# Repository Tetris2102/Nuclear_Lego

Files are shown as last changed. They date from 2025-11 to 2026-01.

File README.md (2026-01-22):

# Nuclear Lego - a Fun and Safe Nuclear Physics Tool

This is intended to be a modular system (base + cubes) which would make it  
easy to perform simple nuclear physics experiments without any radiation  
involved. The project is currently developed as a qualitative tool for  
demonstrations. However there is a large potential for customization, as this  
device is basically a particle transport solver with a physical real-time  
interface (cubes).  

Cubes (4 cm side) can be placed on a rectangular base. Every cube can represent  
either a radioactive source, material, or radiation detector. The base can  
contain 3 layers of 4 by 4 cubes maximum. Every cube can be programmed through  
I2C to change what it represents. Up to 256 types of isotopes and up to 256  
types of materials are supported, extending this is also possible. Radiation  
detectors can be programmed to detect any combination of alpha, beta, gamma  
and neutron radiation.

# Setup instructions
## Raspberry Pi 5:
1. Install g++ and cmake:
``` bash
sudo apt install g++ cmake
```
OpenMP should be included with g++ installation

2. Clone the repository and compile executable:
``` bash
cd ~
mkdir GitHub && cd GitHub
git clone https://github.com/Tetris2102/Nuclear_Lego
cd Nuclear_Lego
cd Particle_Transport
mkdir build && cd build
cmake ..
make
```

3. Ensure the executable has sufficient permissions
``` bash
sudo chmod +x ~/GitHub/Particle_Transport/build/nuclear_lego
```

4. Create systemd service to make the executable launch on system boot
``` bash
sudo nano /etc/systemd/system/nuclear_lego.system
```

Then paste the following into editor:
```
[Unit]
Description=Nuclear Lego main executable
After=network.target

[Service]
ExecStart=~/GitHub/Particle_Transport/build/nuclear_lego

[Install]
WantedBy=multi-user.target
```
Then save, exit and run the following:
``` bash
sudo systemctl daemon-reload
sudo systemctl enable nuclear_lego.service
sudo systemctl start nuclear_lego.service
```

5. Set poweroff button and make it act on the first press
To set poweroff button at GPIO pin 17:
``` bash
sudo nano /boot/firmware/config.txt
```

In editor, add the following line:
```
dtoverlay=gpio-shutdown,gpio_pin=17,gpio_pull=up,debounce=1000
```

To make the poweroff button act on first press:
``` bash
sudo nano /boot/firmware/cmdline.txt
```

In editor, add the following line:
```
command_poweroff=poweroff
```

Then REBOOT with
``` bash
sudo reboot
```

Now you can connect a poweroff button between GPIO pin 17 and ground.

7. (Optional) Enable SSH for easy access to Raspberry Pi
``` bash
sudo raspi-config
```
Go to Interfacing Options -> SSH -> Yes

Now you can access Raspberry Pi 5 through SSH. Assuming username is raspberrypi (default), on MacOS or Linux you can use
``` bash
ssh raspberrypi@raspberrypi.local
```
to access Raspberry Pi if it is one the same network as computer.

## Hardware:
1. Assemble cubes (3d printing, soldering and flashing software on ATTiny85).
It is convenient to use Arduino UNO via Arduino As ISP to program ATTiny 85

2. Assemble the base.
3D print base, then put in poweroff button and power status LED. Mount Raspberry Pi in place with 2 M3x6mm flathead bolts (M3 bolts used everywhere). Solder the 70x90 mm perf board with 2 I2C multiplexers and a level shifter and screw it in with a 3d-printed frame and four M3x6mm flathead bolts. Put header pins in corresponding openings in base lid and solder 30 cm wires with female ports at the other end. Wire everything accordingly. Screw on the lid with eight M3x10mm flathead bolts.

Here is the circuit diagram for base:
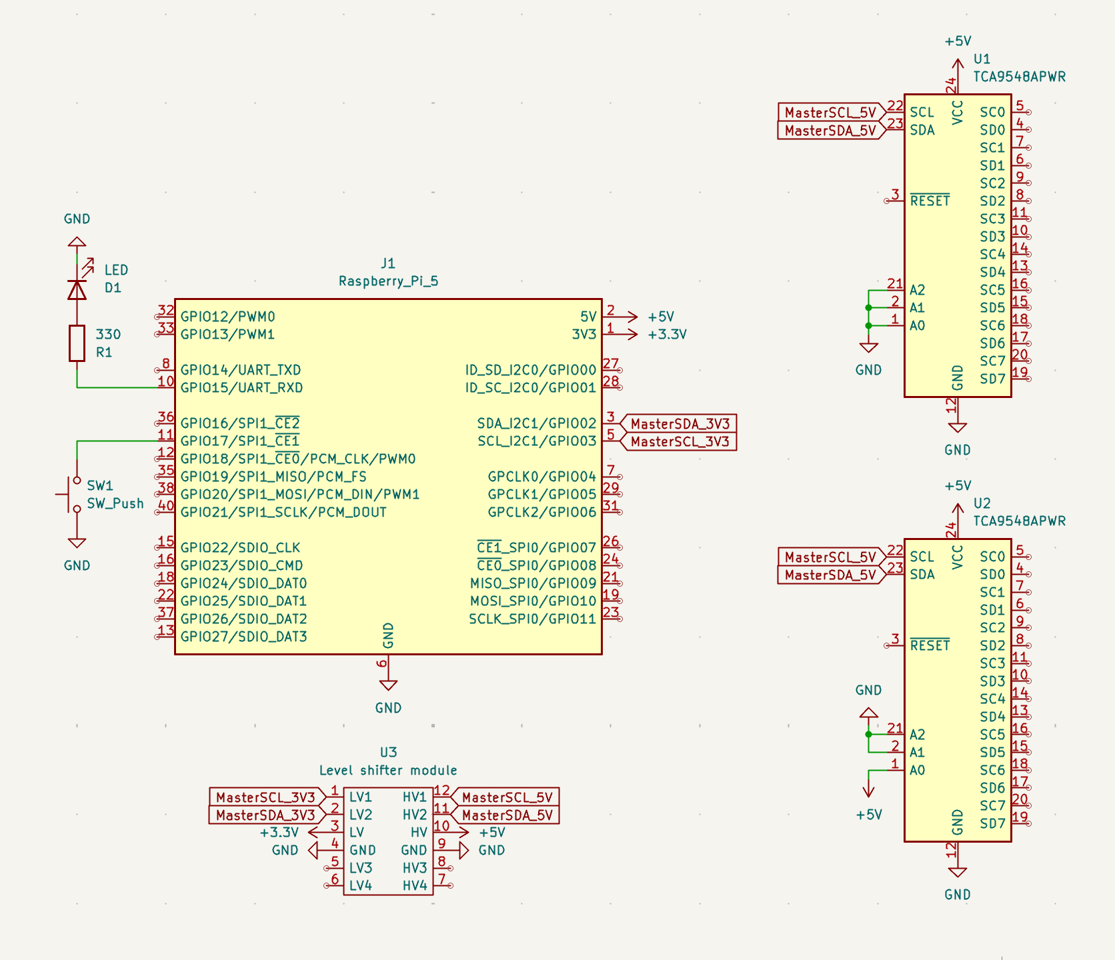
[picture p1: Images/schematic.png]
Failed to load image


(I2C channels 0-7 of multiplexer U1 are connected to voxel slots 0-7, I2C channels 0-7 of multiplexer U2 are connected to voxel slots 8-15)

4. You should be good to go unless any major mistakes were made in the process!

# Usage
1. Now if you have at least two cubes, you can program one to be source and the other to be a detector with an Arduino Uno or Nano via I2C (see cube_attiny85.ino and test_write.ino for programming via I2C).
2. If you put these cubes close to each other on the base, or on top of each other, the detector should produce increased counts with its buzzer.
3. With 3 cubes or more and by adding more reactions/scatters/absorbs to data.cpp you should be able to experiment with particle absorbtion, reflection, production, fission, criticality, and more! Don't forget to recompile after any data was modified for changes to take effect.

# Credits:
1. My parents and my wonderful Special Projects teacher  
2. https://grabcad.com/library/double-sided-fr-4-perfboards-w-m2-corners-1  
3. https://grabcad.com/library/raspberry-pi-5-model-1  
4. https://pip-assets.raspberrypi.com/categories/892-raspberry-pi-5/documents/RP-008347-DS-1-raspberry-pi-5-mechanical-drawing.pdf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

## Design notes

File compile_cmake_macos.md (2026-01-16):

MacOS compilation instructions (error checking ONLY):

1. Install MacPorts (if not already)

2. Install clang and OpenMP through MacPorts:
``` bash
sudo port install g++-15
sudo port install libomp
```

3. Clone the repository in your folder of choice, e.g.:
``` bash
cd ~
git clone https://github.com/Tetris2102/Nuclear_Lego
```

4. Compile using CMake:
Intel MacOS:
``` bash
mkdir Nuclear_Lego/Particle_transport/build
cd Nuclear_Lego/Particle_transport/build
export DCMAKE_CXX_COMPILER=/usr/local/bin/g++-15
cmake -DCMAKE_CXX_COMPILER=/usr/local/bin/g++-15 ..
make
```

Apple Silicon MacOS:
``` bash
mkdir Nuclear_Lego/Particle_transport/build
cd Nuclear_Lego/Particle_transport/build
export DCMAKE_CXX_COMPILER=/opt/homebrew/bin/g++-15
cmake -DCMAKE_CXX_COMPILER=/opt/homebrew/bin/g++-15 ..
make
```

Please note this is for debugging only and you will anyway receive an error:
``` bash
.../pi5_main.cpp:8:10: fatal error: linux/i2c-dev.h: No such file or directory
    8 | #include <linux/i2c-dev.h>
      |          ^~~~~~~~~~~~~~~~~
```

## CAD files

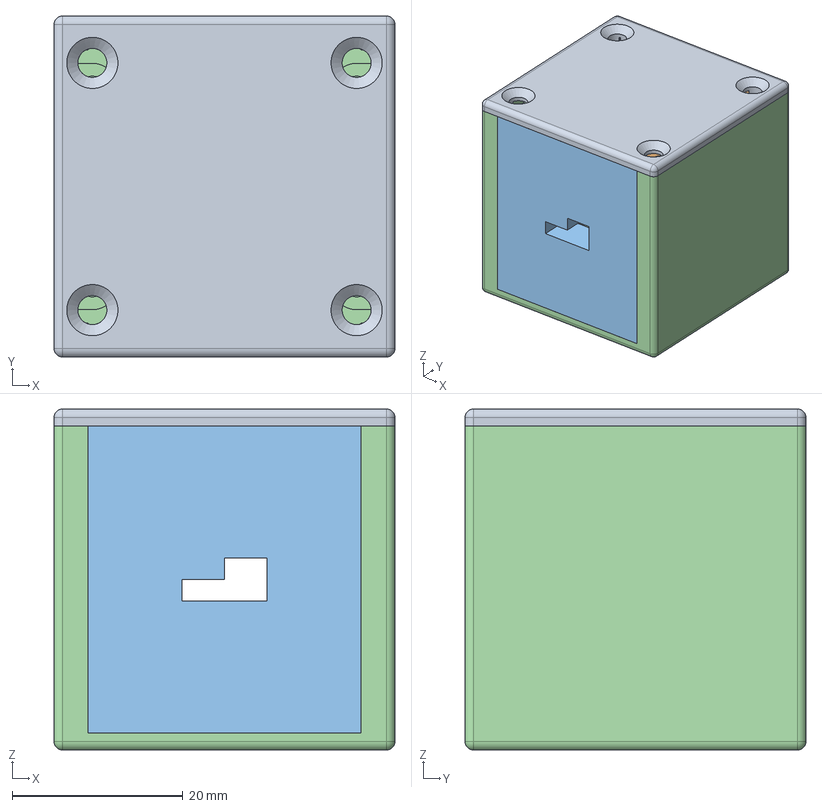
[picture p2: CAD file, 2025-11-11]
Cube_Hardware/case/models/cube_full.step
40.0 x 40.0 x 40.0 mm

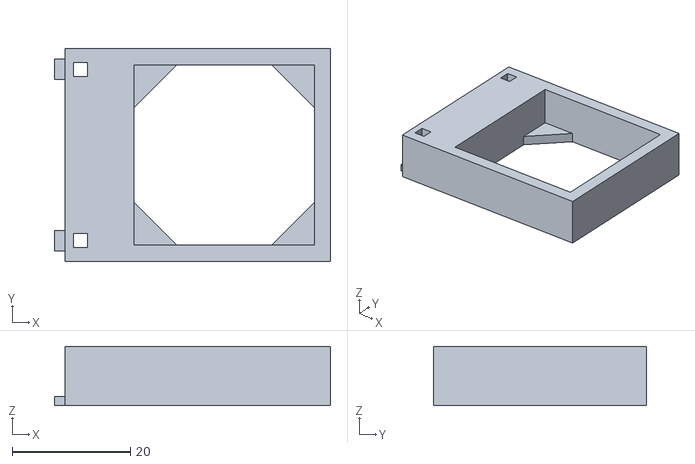
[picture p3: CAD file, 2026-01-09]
Base_Hardware/3D printing sent on Dec.12/FanHolder.stl
46.7 x 36.0 x 10.0

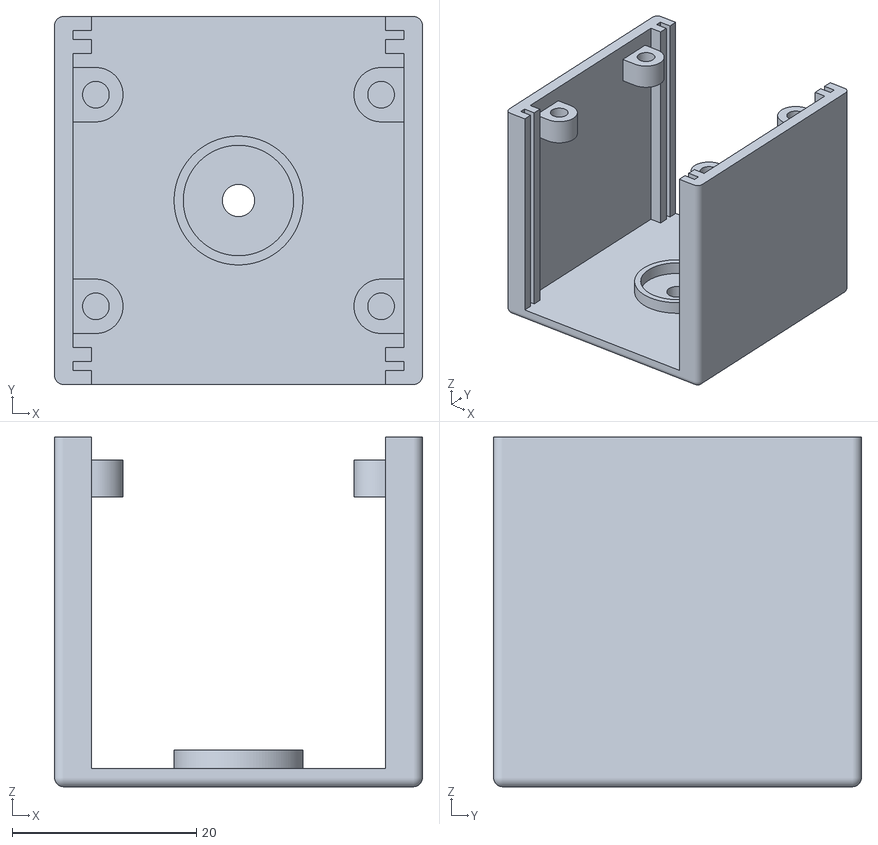
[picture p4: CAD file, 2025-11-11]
Cube_Hardware/case/3dprint/cube_base.stl
40.0 x 40.0 x 38.0

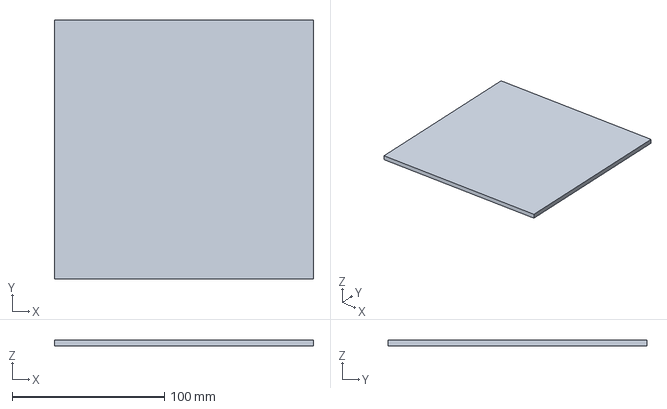
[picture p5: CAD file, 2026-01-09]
Cube_Hardware/case/newAttempt.FCStd
170.0 x 170.0 x 4.00 mm

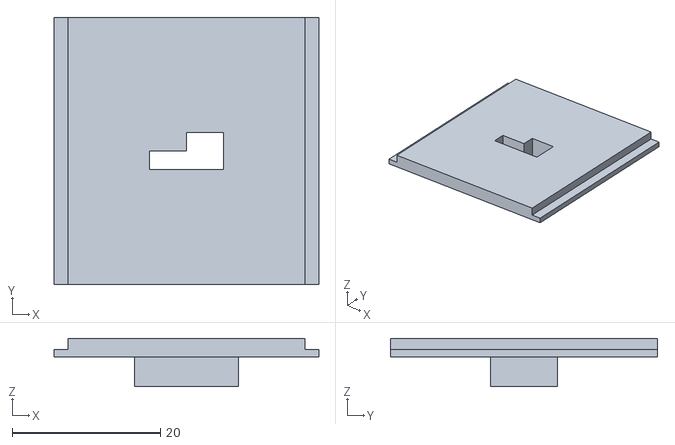
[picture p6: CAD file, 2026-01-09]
Cube_Hardware/case/Nov.17_version/wall1.stl
35.7 x 36.0 x 6.50

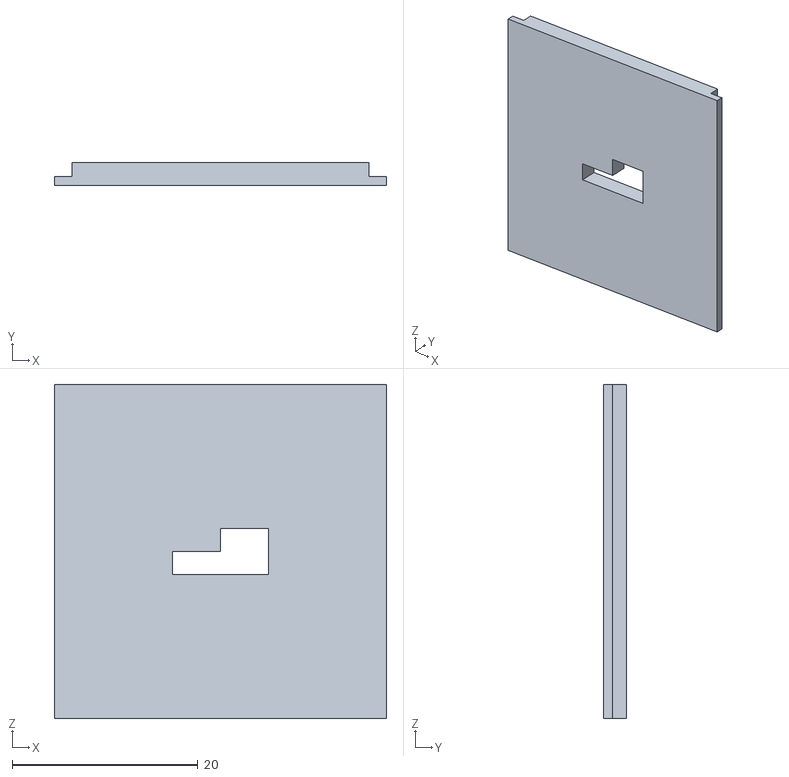
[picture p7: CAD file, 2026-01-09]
Cube_Hardware/case/Nov.24_version/wall2.stl
35.7 x 2.50 x 36.0

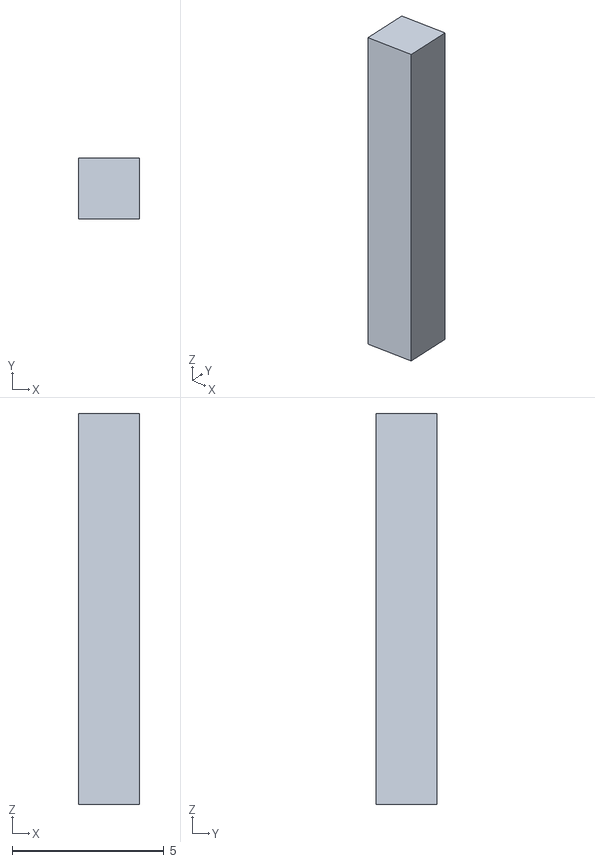
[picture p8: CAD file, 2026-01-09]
Base_Hardware/3D printing sent on Dec.12/Rivet1.stl
2.00 x 2.00 x 12.9

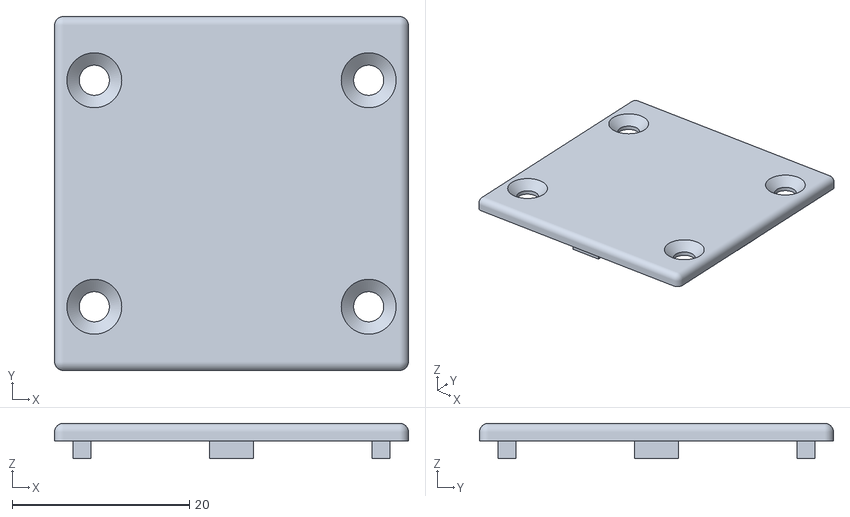
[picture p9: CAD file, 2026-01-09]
Cube_Hardware/case/Nov.24_version/lid.stl
40.0 x 40.0 x 4.00

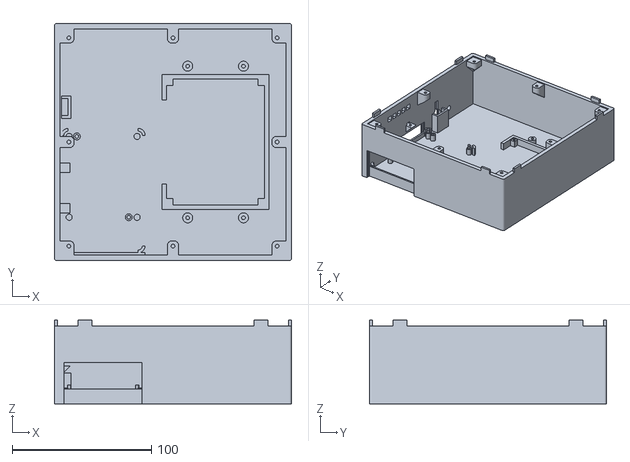
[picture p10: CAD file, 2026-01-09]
Base_Hardware/3D printing sent on Dec.12/BaseBottom.stl
170.0 x 170.0 x 60.0

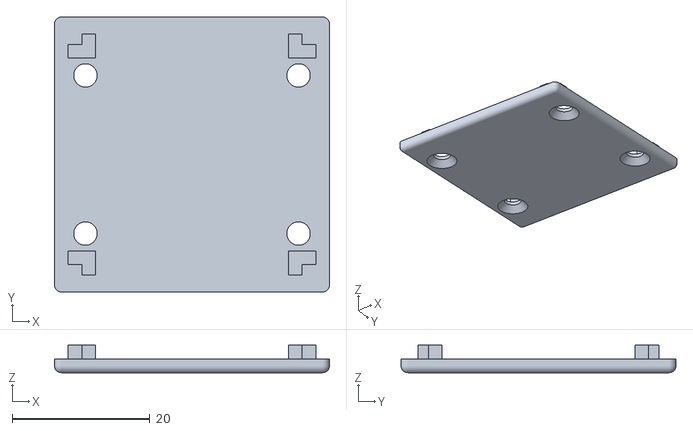
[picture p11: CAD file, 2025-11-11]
Cube_Hardware/case/3dprint/cube_lid.stl
40.0 x 40.0 x 4.00

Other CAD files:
Cube_Hardware/case/Nov.27_version/lid v7.step
Cube_Hardware/case/3dprint/cube_side_female.stl
Cube_Hardware/case/models/cube_case.FCStd
Cube_Hardware/case/Nov.17_version/wall2.stl
Cube_Hardware/case/3dprint/cube_side_male.stl
Cube_Hardware/case/Nov.17_version/base.stl
Cube_Hardware/case/Nov.24_version/body.stl
Base_Hardware/3D printing sent on Dec.12/Rivet2.stl
Base_Hardware/3D printing sent on Dec.12/BaseLid.stl
Base_Hardware/3D printing sent on Dec.12/PCBHolder.stl
Cube_Hardware/case/Nov.17_version/case.step
Cube_Hardware/case/Nov.17_version/lid.stl
Cube_Hardware/case/Nov.24_version/cube_case.step
Cube_Hardware/case/Nov.24_version/wall1.stl
Cube_Hardware/case/old versions/cube_all_improved.step
Cube_Hardware/case/old versions/cube_assembly_Nov.17.f3d
Cube_Hardware/case/old versions/cube_assembly_Nov.17.step
Cube_Hardware/case/old versions/cube_case.FCStd

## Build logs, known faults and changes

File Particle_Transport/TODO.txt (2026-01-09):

-3. Include dist and gen as mandatory constructor parameters in Voxel
    to avoid segmentation fault because of null pointers (instead of using setRNG())
-2. Make all functions const member where possible, especially in Voxel
-1. pointAlongVec() and moveToPointAlong() moved from helpers.cpp
  to particle.cpp -> make corresponding changes - DONE
0. Add moveToPointAlong() to ParticleGroup instead of helpers.cpp - DONE
1. Replace std::array<float, 3> with struct Vec3 - DONE
2. Adjust data types where float is excessive (if needed)
3. Explicitly include all used headers in every implementation file
instead of chaining #include in files - NO NEED?
4. Finish data.cpp

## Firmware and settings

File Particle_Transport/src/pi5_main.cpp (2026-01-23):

// pi5_main.cpp

#include "world.h"
#include "data.cpp"
#include "enums.h"
#include <fcntl.h>
#include <sys/ioctl.h>
#include <linux/i2c-dev.h>
#include <csignal>
#include <array>
#include <vector>
#include <unistd.h>
#include <iostream>
#include <iomanip>
#include <thread>
#include <chrono>

#define MUX1_ADDR 0x70
#define MUX2_ADDR 0x71

using namespace std;

// Global variables
int fd = -1;
std::chrono::duration<float> lastIterationTook;
vector<Material> materials;
vector<IsotopeSample> isotopeSamples;
World* worldPtr = nullptr;

vector<Voxel*> createAirFilledScene(int size) {
    vector<Voxel*> airScene;
    airScene.reserve(size);
    Material air = getM_Air();

    for(uint8_t i=0; i<size; i++) {
        airScene.push_back(new Voxel{MATTER, air});
    }
    return airScene;
}

Material getMaterialFromInt(uint8_t idx) {
    if(idx >= materials.size()) {
        cerr << "Error: Material index " << (int)idx << " out of bounds (size: "
             << materials.size() << ")" << endl;
        return getM_Air();  // Return default material
    }
    return materials[idx];
}

IsotopeSample getSampleFromInt(uint8_t idx) {
    if(idx >= isotopeSamples.size()) {
        cerr << "Error: IsotopeSample index " << (int)idx << " out of bounds (size: "
             << isotopeSamples.size() << ")" << endl;
        return getS_NULL();  // Return default sample
    }
    return isotopeSamples[idx];
}

vector<ParticleType> partsListFromInt(uint8_t val) {
    vector<ParticleType> partsList;
    for(uint8_t i=0; i<8; i++) {
        if(((1 << i) & val) != 0) {
            partsList.push_back(static_cast<ParticleType>(i));
        }
    }
    return partsList;
}

void recordCubeDataTo(vector<Voxel*>& sceneToWrite,
  array<uint8_t, 5>& cubeData, int x, int y) {
    uint8_t z = cubeData[4];

    // Safety check: ensure worldPtr is initialized
    if(worldPtr == nullptr) {
        cerr << "Error: worldPtr is nullptr in recordCubeDataTo()" << endl;
        return;
    }

    // Validate z coordinate (world is 4x4x3, so z must be 0, 1, or 2)
    if(z >= 4) {
        cerr << "Warning: Invalid z coordinate " << (int)z
             << " from cube at (" << x << ", " << y << ")" << endl;
        return;
    }

    // Validate x and y coordinates
    if(x < 0 || x >= 4 || y < 0 || y >= 4) {
        cerr << "Warning: Invalid coordinates ("
            << x << ", " << y << ", " << (int)z << ")" << endl;
        return;
    }

    auto voxelEntryPtr = worldPtr->voxelEntryAt(x, y, z);
    if(voxelEntryPtr == nullptr) {
        cerr << "Error: voxelEntryAt() returned nullptr for ("
             << x << ", " << y << ", " << (int)z << ")" << endl;
        return;
    }

    if(voxelEntryPtr->vPtr == nullptr) {
        cerr << "Error: vPtr is nullptr for voxel at ("
             << x << ", " << y << ", " << (int)z << ")" << endl;
        return;
    }

    auto* voxelPtr = voxelEntryPtr->vPtr;
    VoxelType voxelType = static_cast<VoxelType>(cubeData[0]);

    // // Don't overwrite manually configured detectors (preserve test detectors)
    // // Only update if the cube is actually configured as a detector in hardware
    // if(voxelPtr->getType() == DETECTOR && voxelType != DETECTOR) {
    //     // Skip overwriting - preserve existing detector configuration
    //     return;
    // }
    
    voxelPtr->setType(voxelType);
    voxelPtr->setMaterial(getMaterialFromInt(cubeData[1]));
    if(voxelType == DETECTOR) {
        voxelPtr->setIsotopeSample(getSampleFromInt(cubeData[2]));
        voxelEntryPtr->setPartsDetectable(partsListFromInt(cubeData[3]));
    }
}

void signalInterrupt(int sig) {
    (void)sig;  // Suppress unused parameter warning
    cout << "Exiting program..." << endl;
    if(fd >= 0) {
        close(fd);
    }
    cout << "Done." << endl;
    exit(0);
}

// 4x4x3 (x, y, z) cube world, each cube has a side of 4.0 cm
World world(4, 4, 3, 4.0);

int main() {

    // Handle system shutdown or program termination
    signal(SIGTERM, signalInterrupt);
    signal(SIGINT, signalInterrupt);

    materials = getMaterials();
    isotopeSamples = getIsotopeSamples();
    worldPtr = &world;

    Material air_mat = getM_Air();

    IsotopeSample testSample = getS_Sr90();  // DELETE LINE IN FINAL IMPLEMENTATION
    Voxel testSampleVoxel(SOURCE, air_mat, testSample);  // DELETE LINE IN FINAL IMPLEMENTATION

    vector<Voxel*> scene = createAirFilledScene(48);
    scene[6] = &testSampleVoxel;  // DELETE LINE IN FINAL IMPLEMENTATION
    // scene[6] is at position (2, 1, 0) for 4x4x3 world: index = x + 4*(y + 3*z) = 2 + 4*(1 + 0) = 6

    // Create a test detector near the source (at position 7 = (3, 1, 0))
    Voxel testDetectorVoxel(DETECTOR, air_mat);
    scene[7] = &testDetectorVoxel;  // DELETE LINE IN FINAL IMPLEMENTATION
    world.setScene(scene);

    // Configure detector to detect beta particles (Sr90 emits beta)
    auto* detectorEntry = world.voxelEntryAt(3, 1, 0);
    if(detectorEntry) {
        vector<ParticleType> detectable = {BETA};
        detectorEntry->setPartsDetectable(detectable);
        cout << "Configured detector at (3, 1, 0) to detect BETA particles" << endl;
    }

    const char* dev = "/dev/i2c-1";

    fd = open(dev, O_RDWR);
    if(fd < 0) {
        cerr << "Error: Failed to initialize i2c on master" << endl;
        return 1;
    }

    // Deselect all channels at MUX 1
    unsigned char muxData = 0b00000000;
    if(ioctl(fd, I2C_SLAVE, MUX1_ADDR) < 0) {
        cerr << "Error: Failed to set MUX1 slave address on init" << endl;
        return 1;
    }
    if(write(fd, &muxData, 1) < 1) {
        cerr << "Error: Failed to deselect MUX 2 chanels on init" << endl;
    }

    // Deselect all channels at MUX 2
    if(ioctl(fd, I2C_SLAVE, MUX2_ADDR) < 0) {
        cerr << "Error: Failed to set MUX2 slave address on init" << endl;
        return 1;
    }
    if(write(fd, &muxData, 1) < 1) {
        cerr << "Error: Failed to deselect MUX 2 chanels on init" << endl;
    }

    while(true) {

        auto start = chrono::high_resolution_clock::now();

        // currentCubeData = [voxelType, materialType,
        // sampleType, particlesDetectable, level]
        array<uint8_t, 5> currentCubeData;
        int muxChannelNum = 0;
        for(uint8_t x=0; x<4; x++) {
            for(uint8_t y=0; y<4; y++) {
                muxChannelNum = y * 4 + (x + 1) - 1;  // Channels numbered 0 to 15
                if(muxChannelNum < 8) {

                    // Select MUX1 channel (muxChannelNum 1-8 maps to mux channels 0-7)
                    if(ioctl(fd, I2C_SLAVE, MUX1_ADDR) < 0) {
                        cerr << "Error: Failed to set MUX1 slave address" << endl;
                        continue;
                    }
                    muxData = 1 << muxChannelNum;
                    if(write(fd, &muxData, 1) < 1) {
                        cerr << "Error: Failed to write to MUX1" << endl;
                        continue;
                    }
                    usleep(1000);  // Small delay for mux to settle

                    // Read from each level (addresses 8, 9, 10)
                    for(uint8_t i2c_addr=8; i2c_addr<11; i2c_addr++) {
                        if(ioctl(fd, I2C_SLAVE, i2c_addr) < 0) continue;
                        int bytesRead = read(fd, currentCubeData.data(), 5);
                        if(bytesRead == 5) {
                            recordCubeDataTo(scene, currentCubeData, x, y);
                        } else if(bytesRead > 0) {
                            cerr << "Warning: Only read " << bytesRead
                                << " bytes from 0x" << hex << (int)i2c_addr << endl;
                        }
                    }

                    // Deselect MUX1
                    if(ioctl(fd, I2C_SLAVE, MUX1_ADDR) < 0) {
                        cerr << "Error: Failed to set MUX1 slave address" << endl;
                        continue;
                    }
                    muxData = 0b00000000;
                    if(write(fd, &muxData, 1) < 1) {
                        cerr << "Error: Failed to write to MUX1" << endl;
                    }

                } else if (muxChannelNum < 16) {

                    // Select MUX2 channel
                    if(ioctl(fd, I2C_SLAVE, MUX2_ADDR) < 0) {
                        cerr << "Error: Failed to set MUX2 slave address" << endl;
                        continue;
                    }
                    muxData = 1 << (muxChannelNum - 8);
                    if(write(fd, &muxData, 1) < 1) {
                        cerr << "Error: Failed to write to MUX2" << endl;
                        continue;
                    }
                    usleep(1000);  // Small delay for mux to settle

                    // Read from each level (addresses 8, 9, 10)
                    for(uint8_t i2c_addr=8; i2c_addr<11; i2c_addr++) {
                        if(ioctl(fd, I2C_SLAVE, i2c_addr) < 0) continue;
                        int bytesRead = read(fd, currentCubeData.data(), 5);
                        if(bytesRead == 5) {
                            recordCubeDataTo(scene, currentCubeData, x, y);
                        } else if(bytesRead > 0) {
                            cerr << "Warning: Only read " << bytesRead
                                << " bytes from 0x" << hex << (int)i2c_addr << endl;
                        }
                    }

                    // Deselect MUX2
                    if(ioctl(fd, I2C_SLAVE, MUX2_ADDR) < 0) {
                        cerr << "Error: Failed to set MUX2 slave address" << endl;
                        continue;
                    }
                    muxData = 0b00000000;
                    if(write(fd, &muxData, 1) < 1) {
                        cerr << "Error: Failed to write to MUX2" << endl;
                    }

                } else {

                    cerr << "Error: Invalid multiplexer channel number: "
                        << muxChannelNum << endl;

                }
            }
        }

        int steps = 5;
        float dt = 1.0 / steps;  // Simulating one second total
        for(int i=0; i<steps; i++) {
            world.simulate(dt);
        }

        array<uint8_t, 2> cubeDataToWrite;
        auto detectorEntries = world.getDetectorEntries();
        for(const auto& dEntry : detectorEntries) {

            uint8_t x = dEntry->x;
            uint8_t y = dEntry->y;
            uint8_t z = dEntry->z;

            uint16_t activity = dEntry->getNPartsAbsorbed();
            cubeDataToWrite[0] = activity & 0xFF;  // Least significant byte
            cubeDataToWrite[1] = activity >> 8;    // Most significant byte

            muxChannelNum = y * 4 + (x+1);
            uint8_t i2c_addr = 8 + z;   // Address based on level (z): 8, 9, or 10

            if(muxChannelNum < 9) {

                // Select MUX1 channel (muxChannelNum 1-8 maps to mux channels 0-7)
                if(ioctl(fd, I2C_SLAVE, MUX1_ADDR) < 0) {
                    cerr << "Error: Failed to set MUX1 slave address" << endl;
                    continue;
                }
                muxData = 1 << (muxChannelNum - 1);  // Convert 1-8 to 0-7
                if(write(fd, &muxData, 1) < 1) {
                    cerr << "Error: Failed to write to MUX1" << endl;
                    continue;
                }
                usleep(1000);  // Small delay for mux to settle

                // Write activity to the specific level
                if(ioctl(fd, I2C_SLAVE, i2c_addr) < 0) {
                    cerr << "Error: Failed to set slave address 0x"
                        << hex << (int)i2c_addr << endl;
                    continue;
                }
                if(write(fd, cubeDataToWrite.data(), 2) < 2) {
                    cerr << "Error: Failed to write activity data" << endl;
                }

                // Deselect MUX1
                if(ioctl(fd, I2C_SLAVE, MUX1_ADDR) < 0) {
                    cerr << "Error: Failed to set MUX1 slave address" << endl;
                    continue;
                }
                muxData = 0b00000000;
                if(write(fd, &muxData, 1) < 1) {
                    cerr << "Error: Failed to write to MUX1" << endl;
                }

            } else if(muxChannelNum < 17) {

                // Select MUX2 channel
                if(ioctl(fd, I2C_SLAVE, MUX2_ADDR) < 0) {
                    cerr << "Error: Failed to set MUX2 slave address" << endl;
                    continue;
                }
                muxData = 1 << (muxChannelNum - 8);
                if(write(fd, &muxData, 1) < 1) {
                    cerr << "Error: Failed to write to MUX2" << endl;
                    continue;
                }
                usleep(1000);  // Small delay for mux to settle

                // Write activity to the specific level
                if(ioctl(fd, I2C_SLAVE, i2c_addr) < 0) {
                    cerr << "Error: Failed to set slave address 0x"
                        << hex << (int)i2c_addr << endl;
                    continue;
                }
                if(write(fd, cubeDataToWrite.data(), 2) < 2) {
                    cerr << "Error: Failed to write activity data" << endl;
                }

                // Deselect MUX2
                if(ioctl(fd, I2C_SLAVE, MUX2_ADDR) < 0) {
                    cerr << "Error: Failed to set MUX2 slave address" << endl;
                    continue;
                }
                muxData = 0b00000000;
                if(write(fd, &muxData, 1) < 1) {
                    cerr << "Error: Failed to write to MUX2" << endl;
                }

            } else {

                cerr << "Error: Invalid multiplexer channel number: "
                    << muxChannelNum << endl;

            }
        }

        lastIterationTook = chrono::high_resolution_clock::now() - start;

        if(lastIterationTook.count() <= 1.0f) {
            this_thread::sleep_for(chrono::milliseconds(
                static_cast<int>(
                    950 - round(lastIterationTook.count() * 1000))
                )
            );
        } else {
            cerr << "WARNING: performance drag" << endl;
            cerr << "Last iteration took: " << lastIterationTook.count() << " seconds." << endl;
        }
    }

    close(fd);
    return 0;

    // scan for cubes on each multiplexer channel and record their data in scene - done
    // compute activities - done
    // write activities to cubes - done
}

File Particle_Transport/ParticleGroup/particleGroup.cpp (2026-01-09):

// particle.cpp

#include "particleGroup.h"
#include "../Helpers/helpers.cpp"

void ParticleGroup::setEnergy(float newE) {
    E = newE;
}

float ParticleGroup::getEnergy() const {
    return E;
}

void ParticleGroup::setType(ParticleType newType) {
    type = newType;
}

ParticleType ParticleGroup::getType() const {
    return type;
}

void ParticleGroup::deactivate() {
    exists = false;
}

bool ParticleGroup::isActive() const {
    return exists;
}

void ParticleGroup::setMomentum(Vector3 newMom) {
    mom = newMom;
    normalizeVec3(mom);
}

Vector3 ParticleGroup::getMomentum() const {
    return mom;
}

float ParticleGroup::getMomX() const {
    return mom.x;
}

float ParticleGroup::getMomY() const {
    return mom.y;
}

float ParticleGroup::getMomZ() const {
    return mom.z;
}

void ParticleGroup::setPosition(Vector3 newPos) {
    position = newPos;
}

Vector3 ParticleGroup::getPosition() const {
    return position;
}

float ParticleGroup::getX() const {
    return position.x;
}

float ParticleGroup::getY() const {
    return position.y;
}

float ParticleGroup::getZ() const {
    return position.z;
}

void ParticleGroup::setGroupSize(uint16_t newNumParticles) {
    numParticles = newNumParticles;
}

uint16_t ParticleGroup::getGroupSize() {
    return numParticles;
}

Vector3 ParticleGroup::pointAlongVec(float t) const {
    Vector3 pointAlongVec;

    pointAlongVec.x = position.x + t * mom.x;
    pointAlongVec.y = position.y + t * mom.y;
    pointAlongVec.z = position.z + t * mom.z;

    return pointAlongVec;
}

void ParticleGroup::moveToPointAlong(float t) {
    setPosition(pointAlongVec(t));
}

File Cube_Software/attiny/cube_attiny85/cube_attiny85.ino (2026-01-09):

#include <TinyWireS.h>
#include <EEPROM.h>

#define MAX_LEVEL 2  // Maximum height MINUS 1, so indexing begins from 0

// SDA at PB0
// SCL at PB2
#define PIN_BUZZ 3     // Buzzer pin
#define PIN_LVL_IN A2  // corresponds to PB4

// Corresponding enums are stored in main code (enums.h)
uint8_t voxelType;            // at EEPROM 0
uint8_t materialType;         // at EEPROM 1
uint16_t activity;            // no need to store
uint8_t sampleType;           // at EEPROM 2
// particlesDetectable represents [NEUTRON, GAMMA, BETA, ALPHA]
// (encoded into the 4 least significant bits)
uint8_t particlesDetectable;  // at EEPROM 3
// 1 = maximum sensitivity, 65535 = minimum sensitivity (very unsensitive)
uint8_t sensitivity;          // at EEPROM 4
uint8_t level;

void updateParams();
void reportOnRequest();
void receiveAndStore(uint8_t numBytes);
uint32_t msBetweenDecays(uint16_t activity);
void beepBuzzer();

void setup() {
    pinMode(PIN_BUZZ, OUTPUT);
    pinMode(PIN_LVL_IN, INPUT);

    randomSeed(analogRead(PIN_LVL_IN));

    updateParams();

    TinyWireS.begin(8 + level);  // Use level as I2C address beginning from 8
    // Safe I2C addresses (not reserved): 8-119

    TinyWireS.onRequest(reportOnRequest);
    TinyWireS.onReceive(receiveAndStore);
}

uint32_t decay_interval_ms;
unsigned long last_beep;

void loop() {
    // If voxel is detector
    if(voxelType == 2) {
        TinyWireS_stop_check();

        unsigned long now = millis();

        if(now - last_beep > decay_interval_ms) {
            beepBuzzer();
            decay_interval_ms = msBetweenDecays(activity);
            last_beep = now;
        }
    }
}

void updateParams() {
    // Get parameters from EEPROM on startup
    voxelType = EEPROM.read(0);
    materialType = EEPROM.read(1);
    sampleType = EEPROM.read(2);
    particlesDetectable = EEPROM.read(3);
    sensitivity = min(1, EEPROM.read(4));  // erased EEPROM holds 255

    // Determine voxel's level
    uint16_t v_in = analogRead(PIN_LVL_IN);
    if(v_in > 299) {         // threshold at 577 mV
        level = 0;
    } else if(v_in > 118) {  // threshold at 1.462 V
        level = 1;
    } else {
        level = 2;
    }
}

void reportOnRequest() {
    TinyWireS.write(voxelType);
    TinyWireS.write(materialType);
    // TinyWireS.write(activity & 0xFF);  // Least significant byte first
    // TinyWireS.write(activity >> 8);    // Most significant byte then
    TinyWireS.write(sampleType);
    TinyWireS.write(particlesDetectable);
    TinyWireS.write(level);
}

void receiveAndStore(uint8_t numBytes) {
    if(numBytes == 2) {
        activity = TinyWireS.read() | (TinyWireS.read() << 8);
    } else if(numBytes == 7) {
        voxelType = TinyWireS.read();
        materialType = TinyWireS.read();
        activity = TinyWireS.read() | (TinyWireS.read() << 8);
        sampleType = TinyWireS.read();
        particlesDetectable = TinyWireS.read();
        sensitivity = TinyWireS.read();

        EEPROM.update(0, voxelType);
        EEPROM.update(1, materialType);
        EEPROM.update(2, sampleType);
        EEPROM.update(3, particlesDetectable);
        EEPROM.update(4, sensitivity);
    }
}

uint32_t msBetweenDecays(uint16_t activity) {
    if(activity > 500) activity = 500;  // 500 decays/second max
    // Handle background radiation in case activity is small
    if(activity == 0) activity = 1;

    // Poisson time scaling with random number generator
    uint16_t r = random(1, 65535);

    uint32_t U = r;
    uint32_t diff = 65535 - U;
    uint32_t ln_approx = diff + (diff * diff) / (2 * 65535) +
      (diff * diff * diff) / (3 * 65535 * 65535);

    uint16_t mean_ms = 1000UL / activity;
    // First compute in uint32_t to avoid overflow behaviour
    uint32_t result = (mean_ms * ln_approx) / ((uint16_t)65535 * sensitivity);

    return result;
}

void beepBuzzer() {
    for(uint8_t i = 0; i<20; i++) {
        digitalWrite(PIN_BUZZ, HIGH);
        delayMicroseconds(125);
        digitalWrite(PIN_BUZZ, LOW);
        delayMicroseconds(125);
    }
}

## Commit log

2025-10-03 Code improvements and fixes
    [voxel.cpp]
2025-10-10 Working worldTest.cpp
    To compile, run
    g++ worldTest.cpp ../Vector3/vector3.cpp ../Particle/particle.cpp ../XSTable/xstable.cpp ../Data/data.cpp ../Helpers/helpers.cpp ../IsotopeSample/isotopeSample.cpp ../Material/material.cpp ../Voxel/v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
2025-10-14 Fix isotopeSample.cpp
    Fix source emission direction being biased
    [world.cpp]
2025-10-21 Add Arduino Uno/Nano test code
2025-10-21 Compile code for ATtiny85 and Arduino Nano
2025-10-24 Fix ATTiny85 cube code
    [cube_attiny85.ino]
2025-10-27 Running without errors
    But shows 0 particles absorbed for both detectors (worldTestDistance.cpp)
    [voxel.cpp, world.cpp]
2025-10-30 Works
    Have to compile with g++ -O1, not -O2 or -O3, otherwise determinism issues. The code works, gives identical results for the same seed. Issues: multithreading is the same speed as single thread (probably caused by too many mutexes).
    [voxel.cpp, world.cpp]
2025-11-07 Begin designing cube case
    [cube_case.FCStd]
2025-11-08 Develop cube case
    [cube_case.FCStd]
2025-11-08 Design cube case
    [cube_case.FCStd]
2025-11-08 Cube case v. 1
    [cube_case.FCStd]
2025-11-08 Cube case fixes
    [cube_case.FCStd]
2025-11-10 Fix cube not reading level
    [arduinoTestCode.ino, cube_attiny85.ino, searchForDevices.ino]
2025-11-11 Work on cube case
    [cube_case.FCStd]
2025-11-11 Make files for 3D printing
    [cube_base.stl, cube_case.FCStd, cube_full.step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]
2025-11-13 Begin making freecad model of base
    [base.FCStd]
2025-11-13 Work on FreeCAD base model
    [base.FCStd]
2025-11-16 Fix important bug
    Fix bug in cube_attiny85.ino that didn't allow for proper communication
    [base.FCStd, cube_all_improved.step, cube_case.FCStd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]
2025-11-18 Improve cube case design
    [base.stl, case.step, cube_all_improved.step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]
2025-11-22 Fix i2c scanning code for pi5
    [pi5_scan_i2c.cpp]
2025-11-22 Develop base CAD model and cube attiny85 code
    [base.FCStd, cube_all_improved.step, newAttempt.FCStd]
2025-11-23 Develop CAD model of base
    [base.FCStd]
2025-11-24 Work on CAD model of base
    [base.FCStd]
2025-11-25 3D model and important change to cube attiny85 code
    [base.FCStd, body.stl, cube_case.step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]
2025-11-25 Work on base CAD model
    [base.FCStd]
2025-11-26 Work on CAD model of base
    Make all self-tapping holes (M3) 2.7 mm inner diameter
    [base.FCStd]
2025-11-27 Work on CAD models
    Add new clearance to cube walls, work on CAD model of base
    [base.FCStd, lid v7.step]
2025-12-02 Begin work on pi5_main.cpp
    [base.FCStd]
2025-12-09 Export .stl files, NOT FINAL
    [BaseBottom.stl, BaseLid.stl, FanHolder.stl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]
2025-12-09 Export .stl files of base
    [BaseBottom.stl, BaseLid.stl, FanHolder.stl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]
2025-12-12 Export .stl files for printing
    Add ventilation openings to base.FCStd and export .stl files for 3D printing (all exported except PowerCover and USBCover)
    [BaseBottom.stl, BaseLid.stl, FanHolder.stl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]
2025-12-19 Fix code and add December report
    Also data for 6 materials and 6 isotope samples was added to data.cpp
    [voxel.cpp, world.cpp]
2026-01-06 Works again
    Reverted World, Voxel, IsotopeSample and XSTable classes to commit 1f87d9f. For compile instructions, see Particle_Transport/World/compile_g++.txt
    [pi5_scan_i2c.cpp, voxel.cpp, world.cpp]
2026-01-08 Experiment with bug fixes
    [voxel.cpp, world.cpp]
2026-01-08 Revert "Experiment with bug fixes"
    This reverts commit f2282e40344105ec1fd485113c92dddc702fa76a.
    [voxel.cpp, world.cpp]
2026-01-08 WORKS
    Fixed bug where detectors won't detect any particles unless they have at least one common vertex with the source voxel. Added epsilon clearance to Voxel::intersects(), Voxel::intersectParams() and World::voxelEntryAtPos(). Fixed World::getVoxelCoordVec3()
    [particleGroup.cpp, voxel.cpp, world.cpp]
2026-01-10 Compiles on linux
    pi5_main.cpp compiles without errors on linux
    [pi5_main.cpp, world.cpp]
2026-01-13 Should compile
    Should compile on linux (raspberry pi), does not compile with cmake on macos because OpenMP is not found
2026-01-14 Fix corrupted files
    Fixed pi5_main.cpp, world.cpp and world.h
    [pi5_main.cpp, world.cpp]
2026-01-16 Add setup instructions for Raspberry Pi 5
    Added detailed setup instructions for Raspberry Pi 5 and hardware assembly.
2026-01-16 Update compile_cmake_macos.md with debugging note
    Added a note regarding a debugging error related to missing linux/i2c-dev.h.
2026-01-19 Update README with startup and poweroff button instructions
    Added instructions for launching the executable at startup and configuring the poweroff button.
2026-01-19 Revise SSH access instructions in README
    Updated instructions for enabling SSH access to Raspberry Pi.
2026-01-22 Update README with circuit diagram and instruction edits
    Added circuit diagram reference and clarified instructions.
2026-01-23 Hopefully fix segmentation fault
    [pi5_main.cpp]
